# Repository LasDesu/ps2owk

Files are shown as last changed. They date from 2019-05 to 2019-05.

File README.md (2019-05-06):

# ps2owk
PS/2 to One-Wire-Keyboard adapter.

Adapter for various retro computer keyboards using only one wire for data transfer. One hardware - multiple firmware.
Currently supported:
- PC-8801MA (type C keyboard, I guess)
- FM-77AV

Original project page: http://zxdesu.byethost32.com/2018/02/13/pc-8801-keyboard-adapter/

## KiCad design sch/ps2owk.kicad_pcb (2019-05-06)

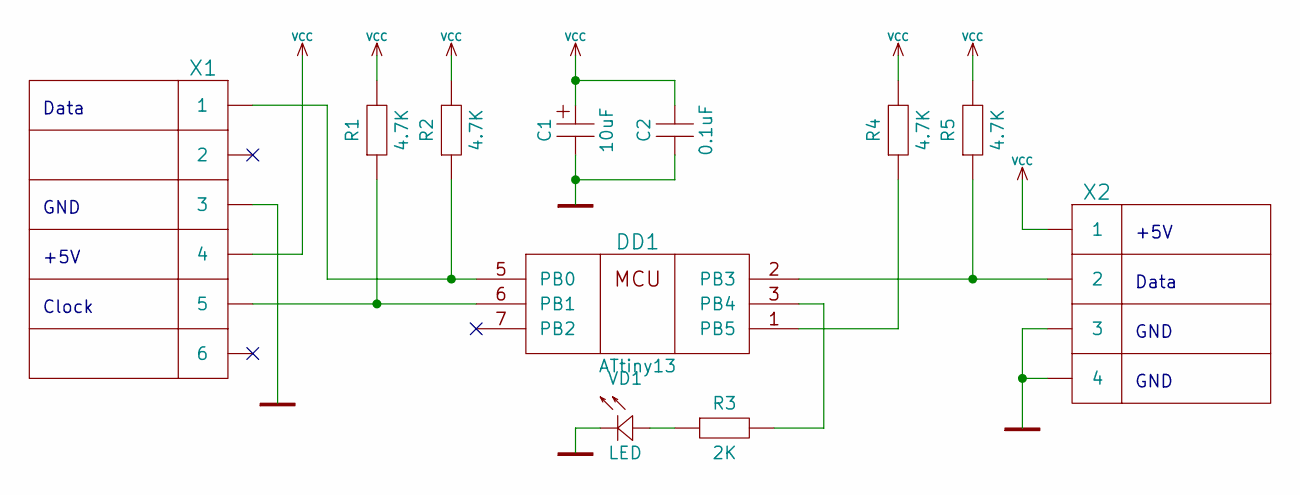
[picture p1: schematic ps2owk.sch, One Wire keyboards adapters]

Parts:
C1: 10uF; CP_Radial_D5.0mm_P2.50mm
C2: 0.1uF; C_0805_HandSoldering
DD1: ATtiny13; DIP-8
R1, R2, R4, R5: 4.7K; R_0805_HandSoldering
R3: 2K; R_0805_HandSoldering
VD1: LED; LED_D3.0mm
X1: CONN-6; Mini_din6
X2: CONN-4; Socket_Strip_Straight_1x04_Pitch2.54mm

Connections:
GND: C1.2, C2.1, DD1.4 (GND), VD1.1, X1.3, X2.3, X2.4
unnamed: DD1.1 (PB5), R4.1
unnamed: DD1.2 (PB3), R5.1, X2.2
unnamed: DD1.3 (PB4), R3.2
unnamed: DD1.5 (PB0), R2.1, X1.1
unnamed: DD1.6 (PB1), R1.1, X1.5
unnamed: R3.1, VD1.2
VCC: C1.1, C2.2, DD1.8 (VCC), R1.2, R2.2, R4.2, R5.2, X1.4, X2.1

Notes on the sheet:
Data
GND
+5V
Clock

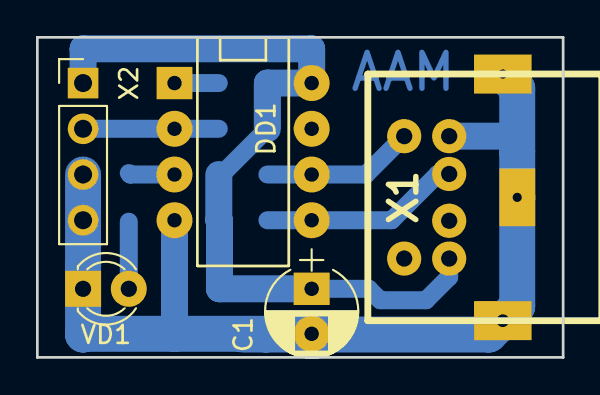
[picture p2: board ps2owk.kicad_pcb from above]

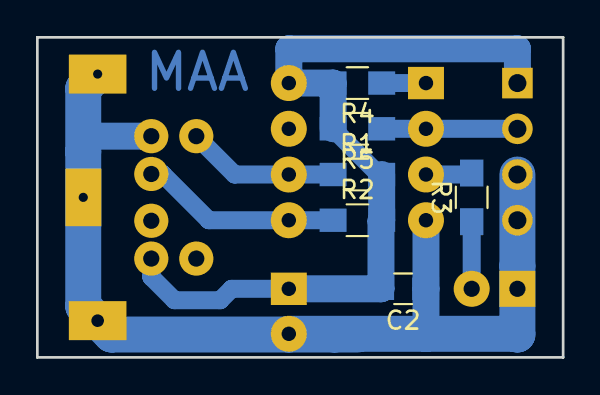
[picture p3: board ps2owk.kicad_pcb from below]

Board: 2 copper layers, 29.2 x 17.8 mm, 11 parts (6 on the bottom side), 8 nets.

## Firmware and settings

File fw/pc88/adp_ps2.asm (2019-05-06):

.ifdef DEVKIT

.message "Compiling ATmega328P based development kit version"
.include "m328Pdef.inc"

.equ	sys_freq	= 8000000

.equ	KBD_PORT	= PORTB
.equ	KBD_DDR		= DDRB
.equ	KBD_PIN		= PINB0

.equ	PS_PORT		= PORTC
.equ	PS_DDR		= DDRC
.equ	PS_PINS		= PINC
.equ	PS_Data		= PINC0
.equ	PS_Clock	= PINC1

.equ	LED_PORT	= PORTC
.equ	LED_PIN		= PINC5

.else

.message "Compiling ATtiny13 based final device version"
.include "tn13def.inc"

.equ	sys_freq	= 9600000

.equ	KBD_PORT	= PORTB
.equ	KBD_DDR		= DDRB
.equ	KBD_PIN		= PINB3

.equ	PS_PORT		= PORTB
.equ	PS_DDR		= DDRB
.equ	PS_PINS		= PINB
.equ	PS_Data		= PINB0
.equ	PS_Clock	= PINB1

.equ	LED_PORT	= PORTB
.equ	LED_PIN		= PINB4

.endif

.def	tmp		= r16
.def	tmph	= r17
.def	tmp2	= r18

.def	m_timer_l	= r28
.def	m_timer_h	= r29

.def	m_flags			= r5
.equ	KBDF_ZENKAKU	= 0
.equ	KBDF_KANA		= 1
.equ	KBDF_CAPS		= 2
.equ	KBDF_BREAK		= 3
.equ	KBDF_EXT		= 4
.equ	TMRF_OVF		= 5

.def	s_store		= r6
.def	uart_val0	= r8
.def	uart_val1	= r9
.def	m_tmp		= r10

.def	ps2_tmp = r16
.def	ps2_tmp2 = r17
.def	ps2_accum = r18
.def	ps2_cksum = r19

.equ	kbd_clk		= 20800
.equ	prescale	= 8
.equ	kbd_div = sys_freq / kbd_clk / prescale

.equ	kbd_buf		= SRAM_START

.CSEG ; ROM
	.org 0
		rjmp	reset

	.org OC0Aaddr
		rjmp	uart_next

;	.org INT_VECTORS_SIZE
reset:
		cli

		; set stack
	.ifdef SPH
		ldi		tmp, high(RAMEND)
		out		SPH, tmp
	.endif
		ldi		tmp, low(RAMEND)
		out		SPL, tmp

		; set I/O
	.ifdef DEVKIT
		ldi		tmp, (0 << LED_PIN) | (0 << PS_Data) | (0 << PS_Clock)
		out		PORTC, tmp
		ldi		tmp, (1 << KBD_PIN)
		out		PORTB, tmp
		ldi		tmp, (1 << LED_PIN) | (0 << PS_Data) | (0 << PS_Clock)
		out		DDRC, tmp
		ldi		tmp, (1 << KBD_PIN)
		out		DDRB, tmp
	.else
		ldi		tmp, (1 << KBD_PIN) | (0 << LED_PIN) | (0 << PS_Data) | (0 << PS_Clock)
		out		PORTB, tmp
		ldi		tmp, (1 << KBD_PIN) | (1 << LED_PIN) | (0 << PS_Data) | (0 << PS_Clock)
		out		DDRB, tmp
	.endif

		; setup keyboard timer period
		ldi		tmp, kbd_div
		out		OCR0A, tmp
		; clear on compare match
		ldi		tmp, (2<<WGM00)
		out		TCCR0A, tmp
		; 8x prescaler
		ldi		tmp, (2<<CS00)
		out		TCCR0B, tmp
		; enable overflow interrupt
		ldi		tmp, (1<<OCIE0A)
	.if TIMSK0 < 0x40
		out		TIMSK0, tmp
	.else
		sts		TIMSK0, tmp
	.endif

		; fill keyboard buffer
		ldi		ZH, high(kbd_buf)
		ldi		ZL, low(kbd_buf)

		ser		tmp
		ldi		tmph, 0xE
fill_buf:
		st		Z+, tmp
		dec		tmph
		brne	fill_buf
		ldi		tmp, 0x7F
		st		Z, tmp

		; set variables
		clr		m_flags
		clr		m_timer_l
		clr		m_timer_h
		ser		tmp
		mov		uart_val0, tmp
		mov		uart_val1, tmp

		sei

		; debug
;		rcall	key_event
;		ldi		ps2_accum, 0x58
;		rcall	process_ps2
;		ldi		ps2_accum, 0x58
;		rcall	process_ps2
;		ldi		ps2_accum, 0x3A
;		rcall	process_ps2
		; debug

		rcall	reset_ps2

main_loop:
		sbi		LED_PORT, LED_PIN

packet_loop:
		; wait for data and process it
		rcall	get_ps2_new
		brcs	main_loop

		cbi		LED_PORT, LED_PIN
		rcall	process_ps2

		; repeat
		rjmp	packet_loop

uart_next:
		in		s_store, SREG
		push	tmp

		; update pin state
		bst		uart_val0, 0
		in		tmp, KBD_PORT
		bld		tmp, KBD_PIN
		out		KBD_PORT, tmp

		; shift bits
		sec
		ror		uart_val1
		ror		uart_val0

		; process timer
		adiw	m_timer_l, 1
		brne	_leave_uart
		ldi		tmp, (1 << TMRF_OVF)
		or		m_flags, tmp

_leave_uart:
		pop		tmp
		out		SREG, s_store

		reti

; =============== S U B R O U T I N E =======================================

delay_500ms:
		ldi		tmp, 25
		mov		r4, tmp

loop_500ms:
		rcall	delay_20ms
		dec		r4
		brne	loop_500ms
		ret

delay_20ms:
		ldi		tmp, 200
		mov		r3, tmp

loop_20ms:
		rcall	delay_100us
		dec		r3
		brne	loop_20ms
		ret

delay_100us:
		ldi		tmp, 100
		rjmp	loop_5us

delay_5us:
		ldi		tmp, 5

loop_5us:
		nop
		rjmp	loop_5us_1

loop_5us_1:
		rjmp	loop_5us_2

loop_5us_2:
		dec		tmp
		brne	loop_5us
		ret

; =============== S U B R O U T I N E =======================================

timeout_2ms:
		; 42 - FFD6
		ldi		tmp, 0xD6
		ldi		tmph, 0xFF
		rjmp	set_timer

timeout_4ms:
		; 83 - FFAD
		ldi		tmp, 0xAD
		ldi		tmph, 0xFF
		rjmp	set_timer

timeout_30ms:
		; 624 - FD90
		ldi		tmp, 0x90
		ldi		tmph, 0xFD
		rjmp	set_timer

timeout_40ms:
		; 832 - FCC0
		ldi		tmp, 0xC0
		ldi		tmph, 0xFC
		rjmp	set_timer

timeout_max:
		; 00 - 256
		clr		tmp
		clr		tmph

set_timer:
		movw	m_timer_l, tmp
		; clear timer overflow flag
		ldi		tmp, ~(1 << TMRF_OVF)
		and		m_flags, tmp
		ret

.include "iface_ps2.inc"

key_event:
		mov		m_tmp, tmp

		; get row address
		mov		tmp, m_tmp
		swap	tmp
		andi	tmp, 0xF
		ldi		ZH, high(kbd_buf)
		ldi		ZL, low(kbd_buf)
		add		ZL, tmp
		clr		tmp
		adc		ZL, tmp

		; get bit mask
		mov		tmp, m_tmp
		andi	tmp, 7
		inc		tmp

		clr		tmph
		sec
get_mask:
		rol		tmph
		dec		tmp
		brne	get_mask

		; load current state
		ld		tmp, Z

		; make or break key
		sbrs	m_tmp, 3
		rjmp	key_make

		or		tmp, tmph
		rjmp	store_keys

key_make:
		com		tmph
		and		tmp, tmph

store_keys:
		; save new state
		st		Z, tmp

send_row_data:
		; prepare data for transmit
		; row
		mov		tmph, m_tmp
		swap	tmph
		andi	tmph, 0xF
		mov		m_tmp, tmph

		; mask
		swap	tmp
		mov		tmph, tmp
		andi	tmph, 0x0F
		andi	tmp, 0xF0
		or		tmp, m_tmp

		; calculate parity
		clr 	m_tmp
		ldi		tmp2, 16
		clc
calc_parity:
		ror		tmph
		ror		tmp
		brcc	parity_zero
		inc		m_tmp
parity_zero:
		dec		tmp2
		brne	calc_parity
		; put last bit back
		ror		tmph
		ror		tmp

		;com		m_tmp	; for odd
		bst		m_tmp, 0
		bld		tmph, 12-8

		; make start/stop bits
		clc
		rol		tmp
		rol		tmph
		ori		tmph, 0xC0

		; set buffer
		cli
		mov		uart_val0, tmp
		mov		uart_val1, tmph
		sei

		ret

; tmp - scancode
process_ps2:
		; check if break
		cpi		ps2_accum, 0xF0
		breq	scan_break

		cpi		ps2_accum, 0xE0
		breq	scan_ext

		sbrc	m_flags, KBDF_EXT
		rjmp	scan_pref_e0

		ldi		tmp, KEY_F7
		cpi		ps2_accum, 0x83	; F7
		breq	process_key88

		cpi		ps2_accum, 0x80
		brsh	scan_done

		; default keymap
		ldi		ZH, high(keymap_default << 1)
		ldi		ZL, low(keymap_default << 1)
		rjmp	get_keycode

scan_pref_e0:
		cpi		ps2_accum, 0x68
		brlo	scan_pref_e0_extra

		cpi		ps2_accum, 0x80
		brsh	scan_done

load_map_e0:
		subi	ps2_accum, 0x68
		ldi		ZH, high(keymap_e0 << 1)
		ldi		ZL, low(keymap_e0 << 1)
		rjmp	get_keycode

scan_pref_e0_extra:
		ldi		tmp, KEY_RRETURN
		cpi		ps2_accum, 0x5A	; kp enter
		breq	process_key88

		ldi		tmp, KEY_KP_DIV
		cpi		ps2_accum, 0x4A	; kp /
		breq	process_key88

		ldi		tmp, KEY_GRPH
		cpi		ps2_accum, 0x11	; ralt
		breq	process_key88

		ldi		tmp, KEY_ZENKAKU
		cpi		ps2_accum, 0x14	; rctrl
		breq	process_key88

		ldi		tmp, KEY_PC
		cpi		ps2_accum, 0x12	; printscreen
		breq	process_key88

		rjmp	scan_done

scan_ext:
		; mark next scancode as extended
		ldi		tmp, (1 << KBDF_EXT)
		or		m_flags, tmp
		ret

scan_break:
		; mark next scancode as break
		ldi		tmp, (1 << KBDF_BREAK)
		or		m_flags, tmp
		ret

scan_done:
		; clear flags
		ldi		tmp, ~((1 << KBDF_BREAK) | (1 << KBDF_EXT))
		and		m_flags, tmp
		ret

get_keycode:
		; get PC88 keycode from keymap
		add		ZL, ps2_accum
		clr		tmp
		adc		ZH, tmp
		lpm		tmp, Z
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

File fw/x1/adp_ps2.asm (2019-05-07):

; based on info from http://kyouichisato.blogspot.com/2014/07/sharp-x1-ps2.html
; and previous project: http://zxdesu.byethost32.com/2018/02/13/pc-8801-keyboard-adapter/

.ifdef DEVKIT

.message "Compiling ATmega328P based development kit version"
.include "m328Pdef.inc"

.equ	sys_freq	= 8000000

.equ	KBD_PORT	= PORTB
.equ	KBD_DDR		= DDRB
.equ	KBD_PIN		= PINB0

.equ	PS_PORT		= PORTC
.equ	PS_DDR		= DDRC
.equ	PS_PINS		= PINC
.equ	PS_Data		= PINC0
.equ	PS_Clock	= PINC1

.equ	LED_PORT	= PORTC
.equ	LED_PIN		= PINC5

.else

.message "Compiling ATtiny25 based final device version"
.include "tn25def.inc"

.equ	sys_freq	= 9600000

.equ	KBD_PORT	= PORTB
.equ	KBD_DDR		= DDRB
.equ	KBD_PIN		= PINB3

.equ	PS_PORT		= PORTB
.equ	PS_DDR		= DDRB
.equ	PS_PINS		= PINB
.equ	PS_Data		= PINB0
.equ	PS_Clock	= PINB1

.equ	LED_PORT	= PORTB
.equ	LED_PIN		= PINB4

.endif

.def	tmp		= r16
.def	tmph	= r17
.def	tmp2	= r18

.def	s_store		= r5

.def	m_flags			= r6
.equ	KBDF_CTRL		= 0
.equ	KBDF_SHIFT		= 1
.equ	KBDF_KANA		= 2	; locked
.equ	KBDF_CAPS		= 3	; locked
.equ	KBDF_GRAPH		= 4
.equ	TMRF_OVF		= 5
.equ	PS2F_BREAK		= 6
.equ	PS2F_EXT		= 7

.def	m_flags2		= r7

.def	kbd_val_l	= r26
.def	kbd_val_h	= r27
.def	kbd_pos		= r25

.def	m_timer_l	= r8
.def	m_timer_h	= r9
.def	m_timer_inc	= r10

;.def	m_tmp		= r15

.def	ps2_tmp = r16
.def	ps2_tmp2 = r17
.def	ps2_accum = r18
.def	ps2_cksum = r19

.equ	prescale = 1024
.equ	kbd_clk = sys_freq / prescale
.equ	kbd_250u = 250000 / kbd_clk
.equ	kbd_700u = 700000 / kbd_clk
.equ	kbd_750u = 750000 / kbd_clk
.equ	kbd_1000u = 1000000 / kbd_clk
.equ	kbd_1750u = 1750000 / kbd_clk
.equ	kbd_pkt_len = 1 + 16 * 2 + 2


.CSEG ; ROM
	.org 0
		rjmp	reset
	
	.org OC0Aaddr
		rjmp	x1kbd_next

;	.org INT_VECTORS_SIZE
reset:
		cli
		
		; set stack
	.ifdef SPH
		ldi		tmp, high(RAMEND)
		out		SPH, tmp
	.endif
		ldi		tmp, low(RAMEND)
		out		SPL, tmp
		
		; set I/O
	.ifdef DEVKIT
		ldi		tmp, (0 << LED_PIN) | (0 << PS_Data) | (0 << PS_Clock)
		out		PORTC, tmp
		ldi		tmp, (1 << KBD_PIN)
		out		PORTB, tmp
		ldi		tmp, (1 << LED_PIN) | (0 << PS_Data) | (0 << PS_Clock)
		out		DDRC, tmp
		ldi		tmp, (1 << KBD_PIN)
		out		DDRB, tmp
	.else
		ldi		tmp, (1 << KBD_PIN) | (0 << LED_PIN) | (0 << PS_Data) | (0 << PS_Clock)
		out		PORTB, tmp
		ldi		tmp, (1 << KBD_PIN) | (1 << LED_PIN) | (0 << PS_Data) | (0 << PS_Clock)
		out		DDRB, tmp
	.endif
		
		; setup keyboard timer period
		ser		tmp
		out		OCR0A, tmp
		; clear on compare match
		ldi		tmp, (2<<WGM00)
		out		TCCR0A, tmp
		; 1024x prescaler
		ldi		tmp, (5<<CS00)
		out		TCCR0B, tmp
		; enable overflow interrupt
		ldi		tmp, (1<<OCIE0A)
	.ifdef DEVKIT
		sts		TIMSK0, tmp
	.else
		out		TIMSK, tmp
	.endif
		
		; set variables
		ldi		tmp, 0x5F
		mov		m_flags, tmp
		clr		m_timer_l
		clr		m_timer_h
		clr		kbd_pos
		ser		tmp
		mov		kbd_val_l, tmp
		mov		kbd_val_h, tmp
				
		sei

		; debug
;		rcall	key_event
;		ldi		ps2_accum, 0x58
;		rcall	process_ps2
;		ldi		ps2_accum, 0x58
;		rcall	process_ps2
;		ldi		ps2_accum, 0x3A
;		rcall	process_ps2
		; debug
		
		rcall	reset_ps2

main_loop:
		sbi		LED_PORT, LED_PIN

packet_loop:
		; wait for data and process it
		rcall	get_ps2_new
		brcs	main_loop
		
		cbi		LED_PORT, LED_PIN
		rcall	process_ps2
		
		; repeat
		rjmp	packet_loop
		
x1kbd_next:
		in		s_store, SREG
		push	tmp
		
		; update timer
		clr		tmp
		add		m_timer_l, m_timer_inc
		adc		m_timer_h, tmp
		brcc	_process_kbd
		ldi		tmp, (1 << TMRF_OVF)
		or		m_flags, tmp
		
_process_kbd:
		tst		kbd_pos
		breq	_leave_x1kbd

		; update pin state
		bst		kbd_pos, 0
		in		tmp, KBD_PORT
		bld		tmp, KBD_PIN
		out		KBD_PORT, tmp
		
		cpi		kbd_pos, kbd_pkt_len
		ldi		tmp, kbd_700u	; start bit
		ldi 	tmph, 700/50
		brsh	_load_timer_val
		
		ldi		tmp, kbd_250u	; data impulse
		ldi 	tmph, 250/50
		sbrs	kbd_pos, 0
		rjmp	_load_timer_val
		
		; shift bits
		sec
		rol		kbd_val_l
		rol		kbd_val_h
		ldi		tmp, kbd_750u	; zero
		ldi 	tmph, 750/50
		brcc	_load_timer_val
		ldi		tmp, kbd_1750u	; one
		ldi 	tmph, 1750/50
		
_load_timer_val:
		out		OCR0A, tmp
		mov		m_timer_inc, tmph
		
		dec		kbd_pos
		brne	_leave_x1kbd
		
		; set 1ms timer updater
		ldi		tmp, kbd_1000u
		out		TCCR0B, tmp
		
_leave_x1kbd:
		pop		tmp
		out		SREG, s_store
		
		reti

x1kbd_send:
		ldi		kbd_pos, kbd_pkt_len
		
		cbi		KBD_PORT, KBD_PIN
		
		ldi		tmp, kbd_1000u
		out		OCR0A, tmp
		clr		tmp
		out		TCNT0, tmp
		
		ret

; =============== S U B R O U T I N E =======================================

delay_500ms:
		ldi		tmp, 25
		mov		r4, tmp

loop_500ms:
		rcall	delay_20ms
		dec		r4
		brne	loop_500ms
		ret

delay_20ms:
		ldi		tmp, 200
		mov		r3, tmp

loop_20ms:
		rcall	delay_100us
		dec		r3
		brne	loop_20ms
		ret

delay_100us:
		ldi		tmp, 100
		rjmp	loop_5us

delay_5us:
		ldi		tmp, 5

loop_5us:
		nop
		rjmp	loop_5us_1

loop_5us_1:
		rjmp	loop_5us_2

loop_5us_2:
		dec		tmp
		brne	loop_5us
		ret

; =============== S U B R O U T I N E =======================================

.equ	timer_ovf_2ms = 0x10000 - (2000/50)
timeout_2ms:
		ldi		tmp, low(timer_ovf_2ms)
		ldi		tmph, high(timer_ovf_2ms)
		rjmp	set_timer

.equ	timer_ovf_4ms = 0x10000 - (4000/50)
timeout_4ms:
		; 83 - FFAD
		ldi		tmp, low(timer_ovf_4ms)
		ldi		tmph, high(timer_ovf_4ms)
		rjmp	set_timer

.equ	timer_ovf_30ms = 0x10000 - (30000/50)
timeout_30ms:
		; 624 - FD90
		ldi		tmp, low(timer_ovf_30ms)
		ldi		tmph, high(timer_ovf_30ms)
		rjmp	set_timer

.equ	timer_ovf_40ms = 0x10000 - (40000/50)
timeout_40ms:
		; 832 - FCC0
		ldi		tmp, low(timer_ovf_40ms)
		ldi		tmph, high(timer_ovf_40ms)
		rjmp	set_timer
		
timeout_max:
		clr		tmp
		clr		tmph

set_timer:
		movw	m_timer_l, tmp
		; clear timer overflow flag
		ldi		tmp, ~(1 << TMRF_OVF)
		and		m_flags, tmp
		ret

.include "iface_ps2.inc"

key_event:
		
		
		; set buffer
		cli
		mov		kbd_val_l, tmp
		mov		kbd_val_h, tmph
		sei

		ret

; tmp - scancode
process_ps2:
		; check if break
		cpi		ps2_accum, 0xF0
		breq	scan_break

		cpi		ps2_accum, 0xE0
		breq	scan_ext
		
		sbrs	m_flags, PS2F_EXT
		rjmp	load_map_base
		
		cpi		ps2_accum, 0x68
		brsh	load_map_ext

load_map_base:
		cpi		ps2_accum, 0x88
		brsh	scan_done

		; default keymap
		ldi		ZH, high(keymap_base << 1)
		ldi		ZL, low(keymap_base << 1)
		rjmp	get_keycode

load_map_ext:
		cpi		ps2_accum, 0x80
		brsh	scan_done
		
		subi	ps2_accum, 0x68
		ldi		ZH, high(keymap_e0_off68 << 1)
		ldi		ZL, low(keymap_e0_off68 << 1)
		rjmp	get_keycode

scan_ext:
		; mark next scancode as extended
		ldi		tmp, (1 << PS2F_EXT)
		or		m_flags, tmp
		ret

scan_break:
		; mark next scancode as break
		ldi		tmp, (1 << PS2F_BREAK)
		or		m_flags, tmp
		ret

scan_done:
		; clear flags
		ldi		tmp, ~((1 << PS2F_BREAK) | (1 << PS2F_EXT))
		and		m_flags, tmp
		ret
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

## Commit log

2018-02-17 fix sysfreq on tiny13; fix F7 key
    [adp_ps2.asm]
2018-02-17 element values
    [pc88kbd.kicad_pcb, pc88kbd.sch]
2019-05-06 Rename KiCad files
    [ps2owk.kicad_pcb, ps2owk.sch]
2019-05-06 hw: update schematic
    [ps2owk.kicad_pcb, ps2owk.sch]
2019-05-06 PC88: make LED flashing more distinct
2019-05-07 FM77: place ESC and Break keys more like in original keyboard
